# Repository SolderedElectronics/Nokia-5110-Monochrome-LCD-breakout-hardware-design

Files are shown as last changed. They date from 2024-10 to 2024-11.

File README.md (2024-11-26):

[SKU]: 333000

# --- Product name --- Hardware design

## About the product

| Product name |
| :----------------------------------------------------------: |
|      [Buy --- product name ----](https://www.solde.red/[SKU])      |

------ product description ------

## Repository contents

All Soldered Electronics hardware designed in KiCAD, and repositories are organized in the following way:

- CAD folder - contains KiCAD files (Schematics, Board, Panel Board), sorted by version. Change log lists all changes between versions.
- OUTPUTS - contains useful files, such as Bill of Materials (BOM), PDF of schematics, 3D .step file of the board and gerber files, sorted by version. 
- OUTPUTS -> Compliance - Certificates and useful legal stuff. 

## Want to contribute?

Please feel free to submit a pull request if you have any contributions. We encourage you to submit an issue or pull request if you find a bug. 

## About Soldered

soldered-logo

At Soldered, we design and manufacture a wide selection of electronic products to help you turn your ideas into acts and bring you one step closer to your final project. Our products are intented for makers and crafted in-house by our experienced team in Osijek, Croatia. We believe that sharing is a crucial element for improvement and innovation, and we work hard to stay connected with all our makers regardless of their skill or experience level. Therefore, all our products are open-source. Finally, we always have your back. If you face any problem concerning either your shopping experience or your electronics project, our team will help you deal with it, offering efficient customer service and cost-free technical support anytime. Some of those might be useful for you:

- [Web Store](https://www.soldered.com/shop)
- [Tutorials & Projects](https://soldered.com/learn)
- [Community & Technical support](https://soldered.com/community)

## License info

All Soldered open-source hardware (OSH) is under The TAPR Open Hardware License. Read more in the LICENSE file. 

No warranty - all designs in this repository are distributed in the hope that they will be useful, but without any warranty. They are provided "AS IS", therefore without warranty of any kind, either expressed or implied. The entire quality and performance of what you do with the contents of this repository are your responsibility. In no event, Soldered Electronics will be liable for your damages, losses, including any general, special, incidental or consequential damage arising out of the use or inability to use the contents of this repository. 

## Have fun! 
And thank you from your fellow makers at Soldered Electronics.

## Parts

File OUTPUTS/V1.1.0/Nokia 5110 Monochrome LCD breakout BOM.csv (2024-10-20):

Id | Designator | Package | Quantity | Designation | Supplier and ref
1 | D2,D3,D5,D4 | 0603LED | 4 | White
2 | H2,H4,H1,H3 | HOLE_3.2mm | 4 | HOLE_3.2mm
3 | U2 | Nokia_5110_LCD | 1 | Nokia_5110_LCD
4 | U3 | TXB0104QPWRQ1 | 1 | TXB0104QPWRQ1
5 | C5,C3,C4,C6 | 0603C | 4 | 100n
6 | R3,R1,R4 | 0603R | 3 | 10k
7 | Q2 | SOT-23-3 | 1 | NMOS
8 | R8 | 0603R | 1 | 5k1
9 | JP3,JP1 | SMD-JUMPER-CONNECTED_TRACE_SOLDERMASK | 2 | SMD-JUMPER-CONNECTED_TRACE_SOLDERMASK
10 | K1 | HEADER_MALE_9X1 | 1 | HEADER_MALE_9X1
11 | D1 | 0402LED | 1 | purple
12 | R6,R5,R7,R9 | 0603R | 4 | 10
13 | R2 | 0402R | 1 | 330R
14 | U1 | SOT-23-5 | 1 | SE5218
15 | JP2 | SMD_JUMPER | 1 | SMD_JUMPER
16 | Q1 | SOT-23-3 | 1 | PMOS
17 | C7 | 0603C | 1 | 4u7
18 | C1,C2 | 0603C | 2 | 2u2

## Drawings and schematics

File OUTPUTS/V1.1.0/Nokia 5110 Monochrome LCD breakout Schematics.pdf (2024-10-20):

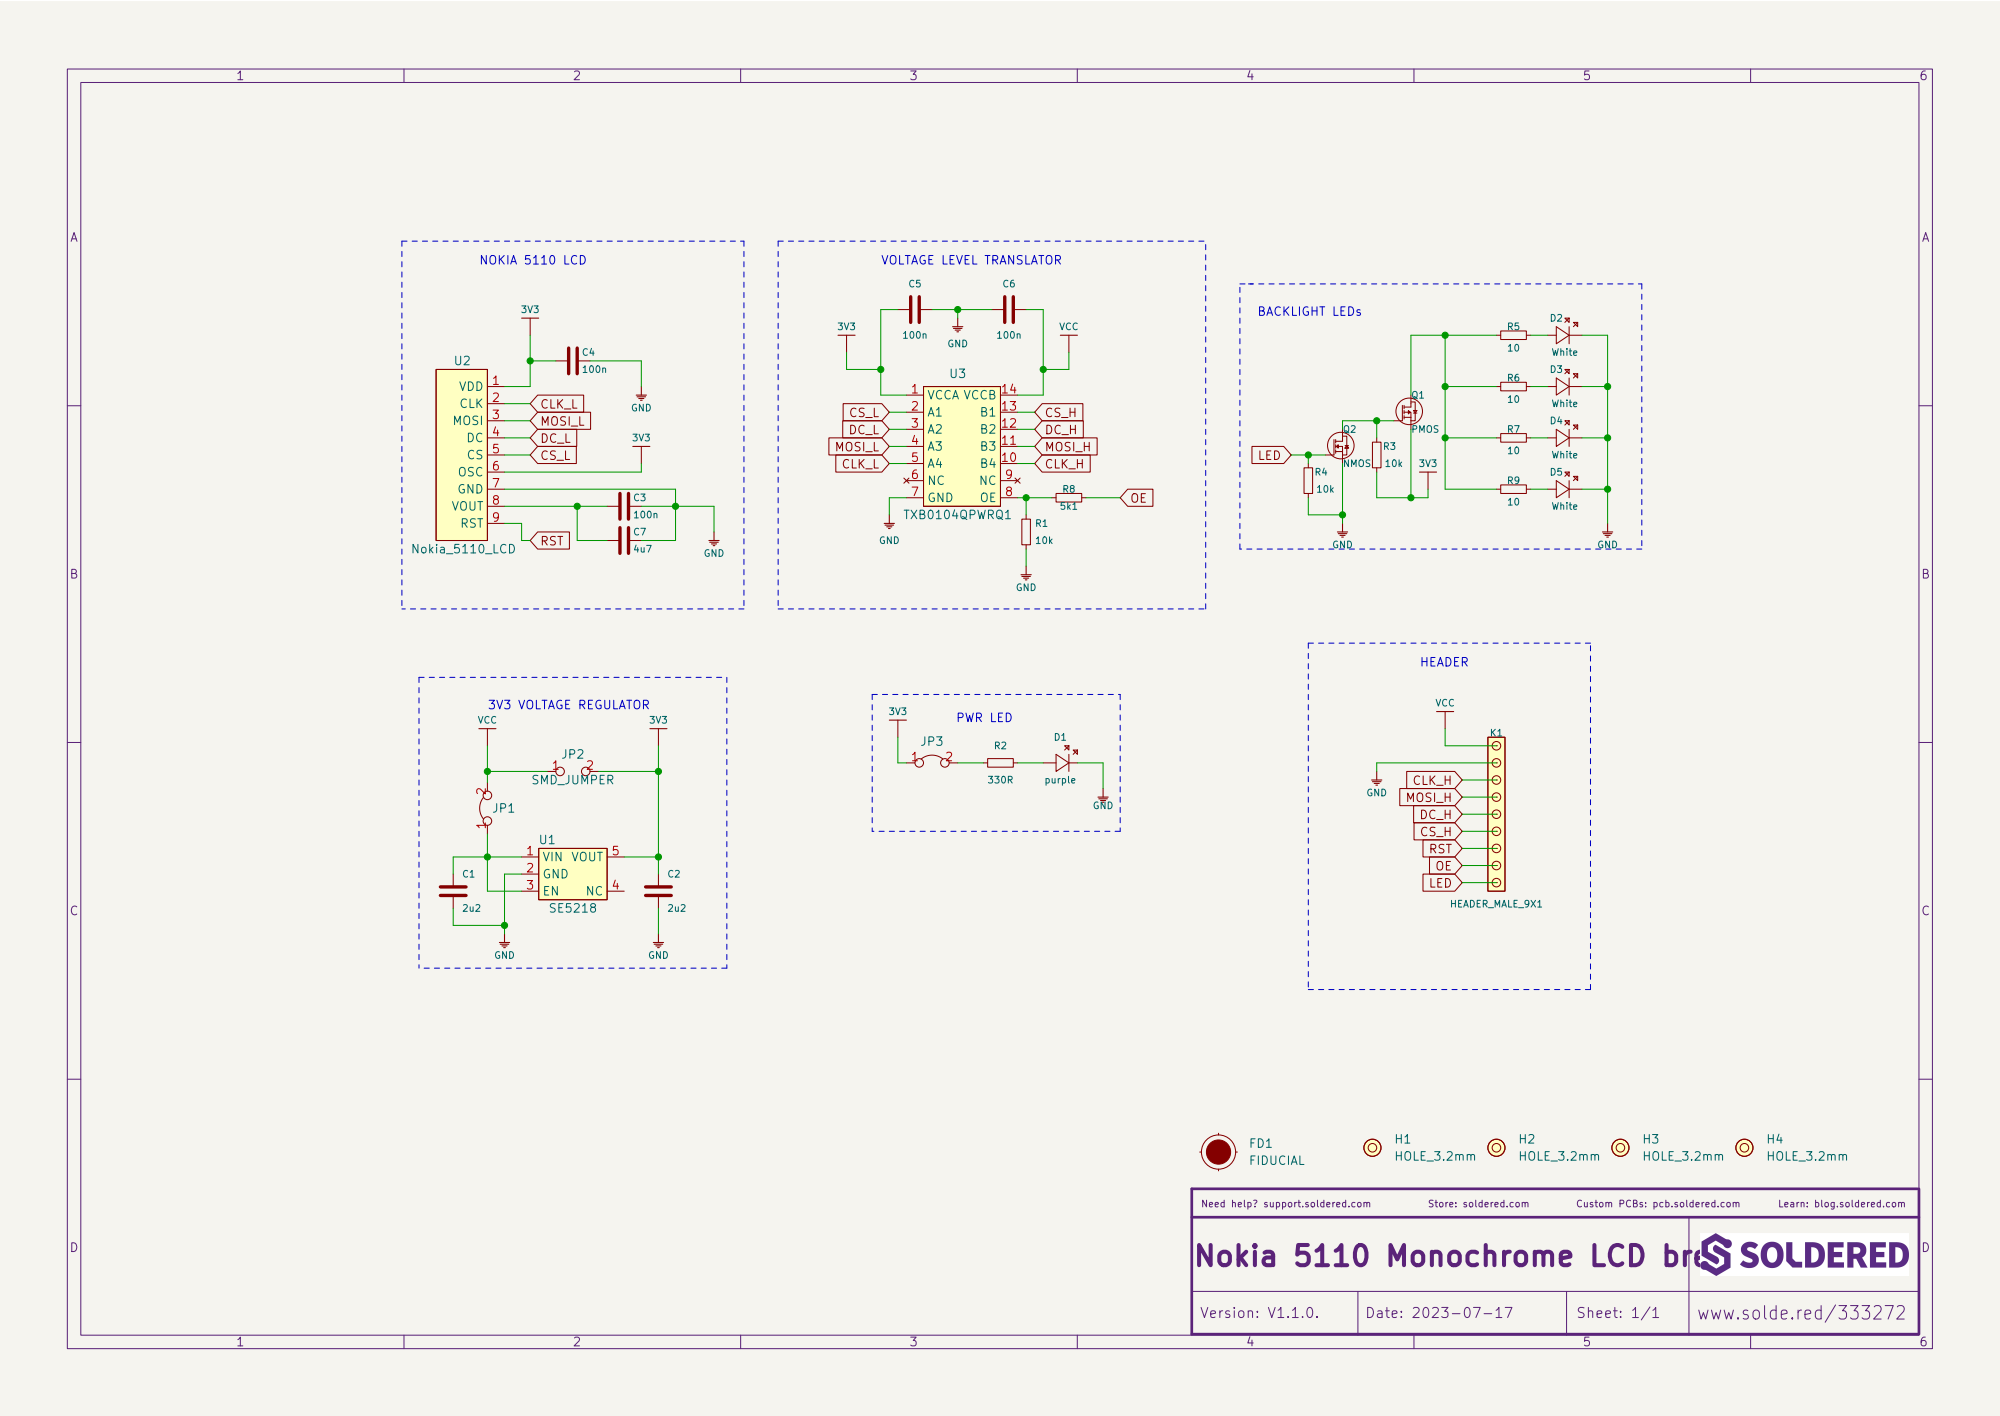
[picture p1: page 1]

BACKLIGHT LEDs PWR LED

Learn: blog.soldered.com

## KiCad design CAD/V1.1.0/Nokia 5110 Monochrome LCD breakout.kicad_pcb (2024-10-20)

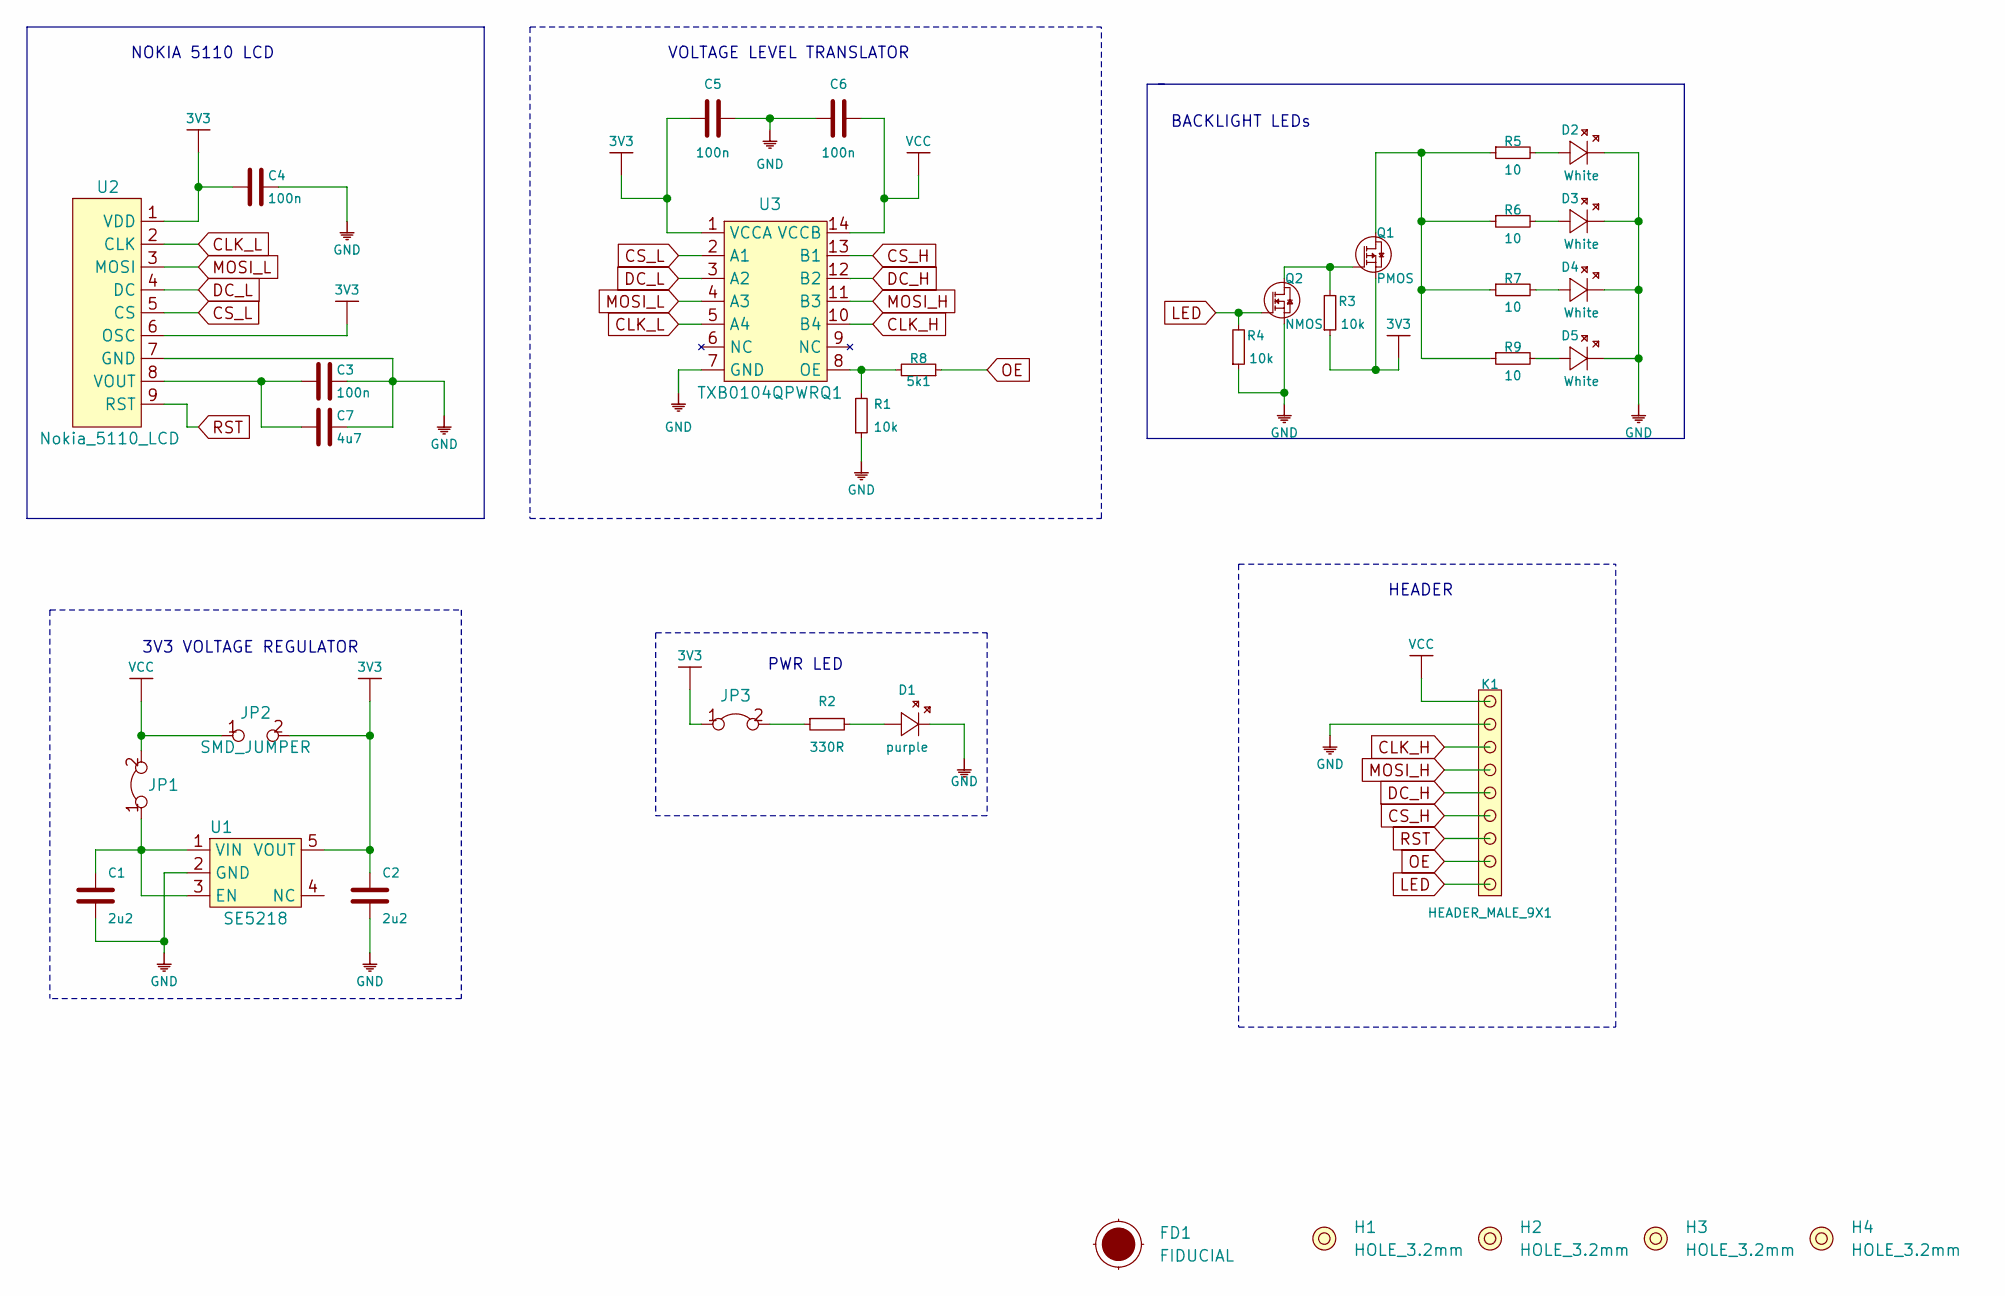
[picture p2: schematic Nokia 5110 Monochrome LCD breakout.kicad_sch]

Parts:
C1, C2: 2u2; 0603C
C3, C4, C5, C6: 100n; 0603C
C7: 4u7; 0603C
D1: purple; 0402LED
D2, D3, D4, D5: White; 0603LED
FD1: FIDUCIAL; FIDUCIAL_23
H1, H2, H3, H4: HOLE_3.2mm
JP1, JP3: SMD-JUMPER-CONNECTED_TRACE_SOLDERMASK
JP2: SMD_JUMPER
K1: HEADER_MALE_9X1
Q1: PMOS; SOT-23-3
Q2: NMOS; SOT-23-3
R1, R3, R4: 10k; 0603R
R2: 330R; 0402R
R5, R6, R7, R9: 10; 0603R
R8: 5k1; 0603R
U1: SE5218; SOT-23-5
U2: Nokia_5110_LCD
U3: TXB0104QPWRQ1

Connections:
3V3: C2.2, C4.2, C5.1, JP2.2, JP3.1, Q1.2 (S), R3.1, U1.5 (VOUT), U2.1 (VDD), U2.6 (OSC), U3.1 (VCCA)
CLK_H: K1.7, U3.10 (B4)
CLK_L: U2.2 (CLK), U3.5 (A4)
CS_H: K1.4, U3.13 (B1)
CS_L: U2.5 (CS), U3.2 (A1)
DC_H: K1.5, U3.12 (B2)
DC_L: U2.4 (DC), U3.3 (A2)
GND: C1.1, C2.1, C3.1, C4.1, C5.2, C6.1, C7.1, D1.2 (K), D2.2 (K), D3.2 (K), D4.2 (K), D5.2 (K), K1.8, Q2.2 (S), R1.1, R4.1, U1.2 (GND), U2.7 (GND), U3.7 (GND)
LED: K1.1, Q2.1 (G), R4.2
MOSI_H: K1.6, U3.11 (B3)
MOSI_L: U2.3 (MOSI), U3.4 (A3)
unnamed: C1.2, JP1.1, U1.1 (VIN), U1.3 (EN)
unnamed: C3.2, C7.2, U2.8 (VOUT)
unnamed: D1.1 (A), R2.2
unnamed: D2.1 (A), R5.2
unnamed: D3.1 (A), R6.2
unnamed: D4.1 (A), R7.2
unnamed: D5.1 (A), R9.2
unnamed: JP3.2, R2.1
unnamed: Q1.1 (G), Q2.3 (D), R3.2
unnamed: Q1.3 (D), R5.1, R6.1, R7.1, R9.1
unnamed: R1.2, R8.2, U3.8 (OE)
OE: K1.2, R8.1
RST: K1.3, U2.9 (RST)
VCC: C6.2, JP1.2, JP2.1, K1.9, U3.14 (VCCB)

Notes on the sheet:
HEADER
BACKLIGHT LEDs
3V3 VOLTAGE REGULATOR
VOLTAGE LEVEL TRANSLATOR
PWR LED
NOKIA 5110 LCD

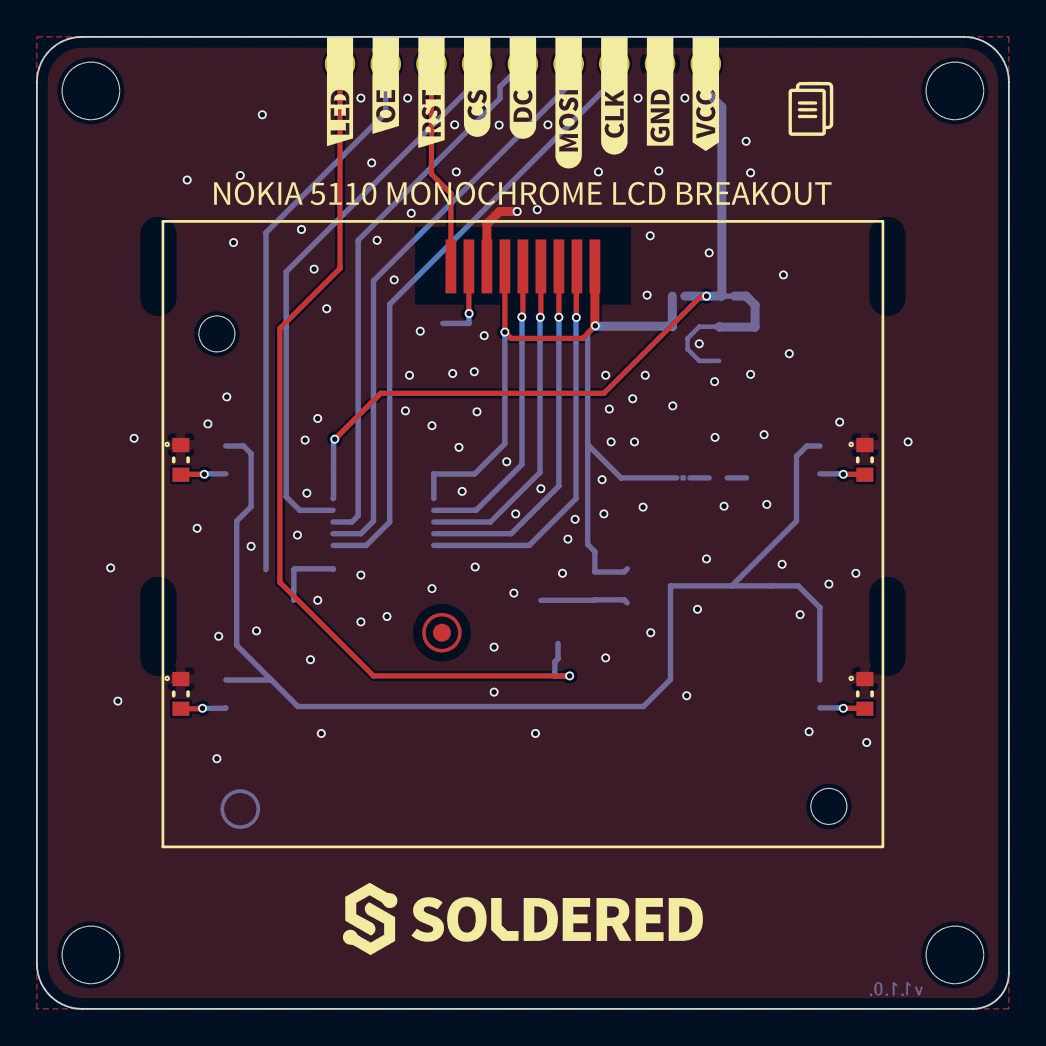
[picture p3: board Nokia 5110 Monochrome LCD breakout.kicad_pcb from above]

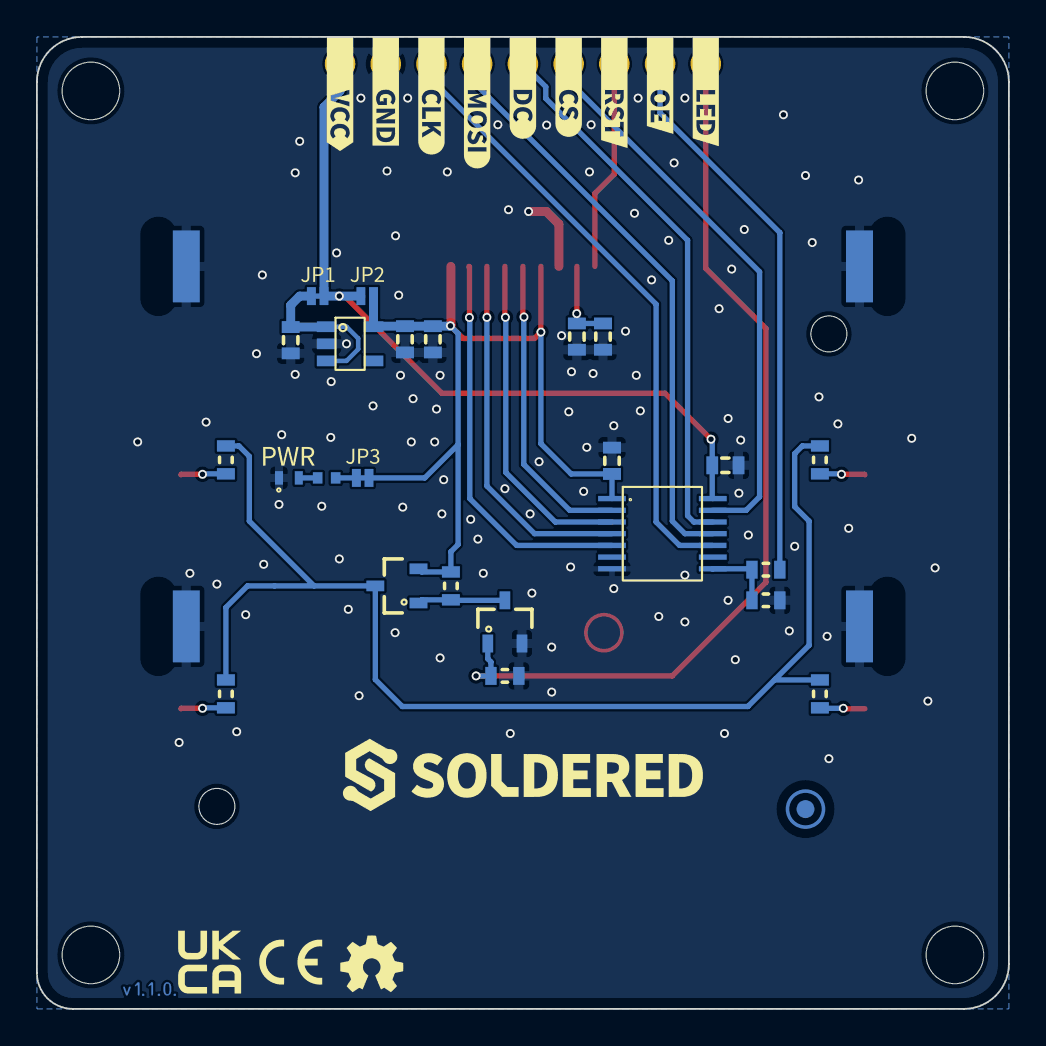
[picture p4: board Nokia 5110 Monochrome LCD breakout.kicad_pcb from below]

Board: 2 copper layers, 54.0 x 54.0 mm, 60 parts (40 on the bottom side), 25 nets.

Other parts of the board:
FD1#2: FIDUCIAL; FIDUCIAL_23
Ref**: Val**; Version1.1.0
kibuzzard-646B4D66: G***; kibuzzard-646B4D66
kibuzzard-640196A4: G***; kibuzzard-640196A4
kibuzzard-640198BB: G***; kibuzzard-640198BB
kibuzzard-640198C6: G***; kibuzzard-640198C6
kibuzzard-640198D2: G***; kibuzzard-640198D2
kibuzzard-640198DB: G***; kibuzzard-640198DB
kibuzzard-640198F2: G***; kibuzzard-640198F2
kibuzzard-6401968D: G***; kibuzzard-6401968D
kibuzzard-6401969B: G***; kibuzzard-6401969B
kibuzzard-6401969E: G***; kibuzzard-6401969E
kibuzzard-6401974E: G***; kibuzzard-6401974E
kibuzzard-6401977A: G***; kibuzzard-6401977A
kibuzzard-6401977E: G***; kibuzzard-6401977E
kibuzzard-6401983D: G***; kibuzzard-6401983D
kibuzzard-6401988B: G***; kibuzzard-6401988B
kibuzzard-6401989A: G***; kibuzzard-6401989A
kibuzzard-64019679: G***; kibuzzard-64019679
kibuzzard-64019690: G***; kibuzzard-64019690
kibuzzard-64019694: G***; kibuzzard-64019694
kibuzzard-64019697: G***; kibuzzard-64019697
kibuzzard-64019785: G***; kibuzzard-64019785
kibuzzard-64019789: G***; kibuzzard-64019789
kibuzzard-64019880: G***; kibuzzard-64019880
